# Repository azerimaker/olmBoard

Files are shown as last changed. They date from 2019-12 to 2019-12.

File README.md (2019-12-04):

# olmBoard v0.1
This is a TPS62840 based, ultra-low quiescent current, highly-efficient, breadboard-friendly buck converter module w/:
- Selectable outputs (1.8-3.3 V)
- 60nA Iq, 150nA @ 100% mode
- 20nA shutdown current 
- 750mA max output current

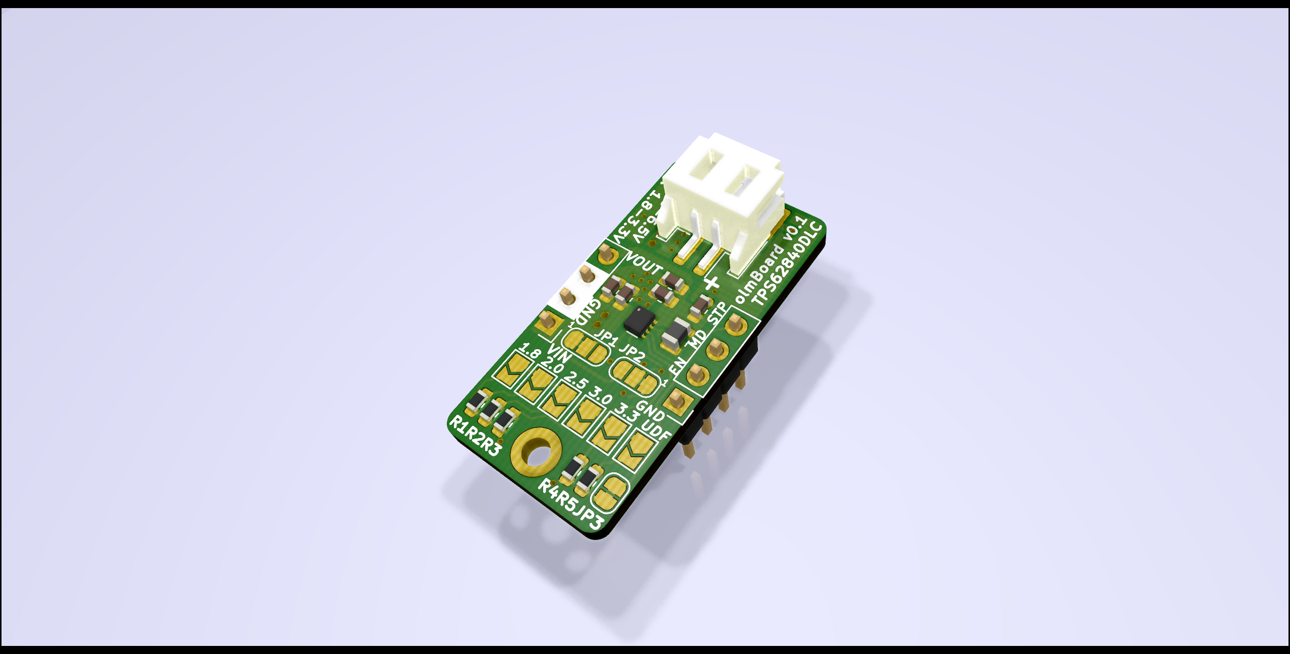
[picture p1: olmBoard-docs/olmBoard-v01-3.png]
olmBoard v0.1


Inital sweep load test results w/ 0.1A and 10 sec increments using EBD-USB load tester. The module works well up to 1A loads (short term), recommended max output current is 750mA. Voltage drop in the graph is due to the USB cable drop, actual voltage is stable around 3.3V up to 1A loads. 

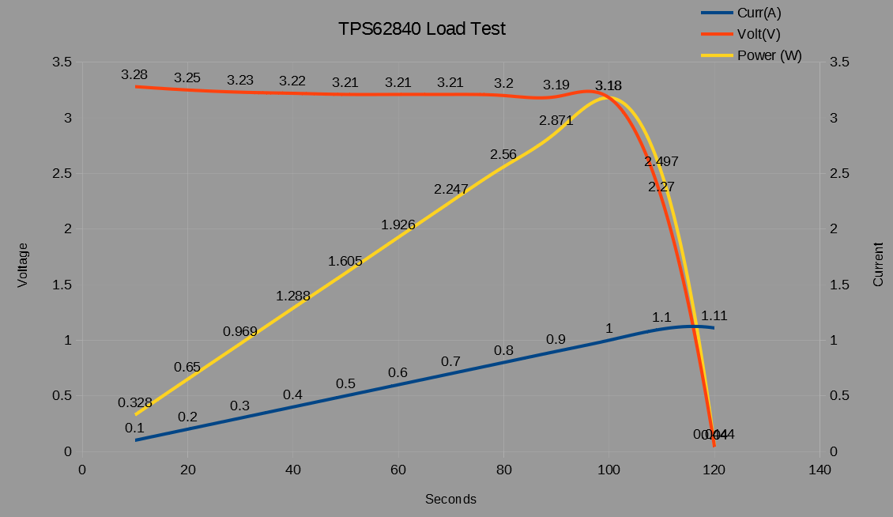
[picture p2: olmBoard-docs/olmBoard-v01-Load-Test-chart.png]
olmBoard v0.1 Load Test Chart


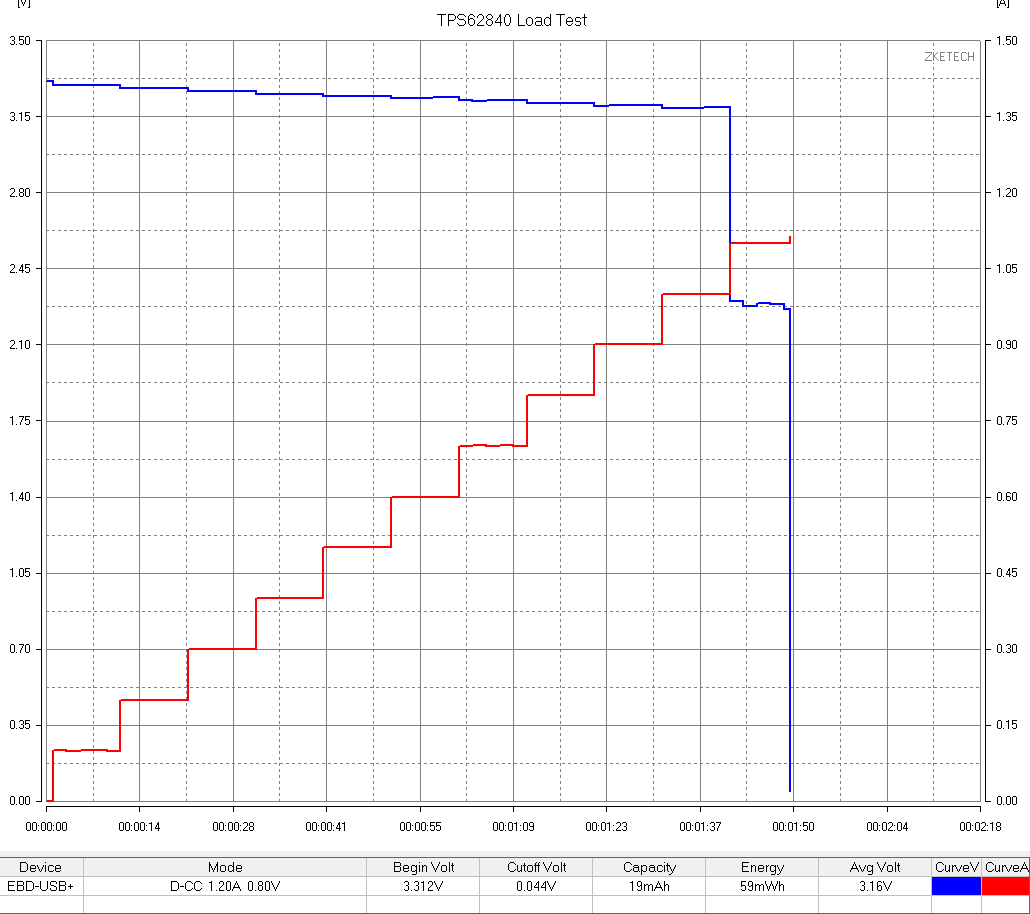
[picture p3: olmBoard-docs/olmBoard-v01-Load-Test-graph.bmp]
olmBoard v0.1 Load Test Graph


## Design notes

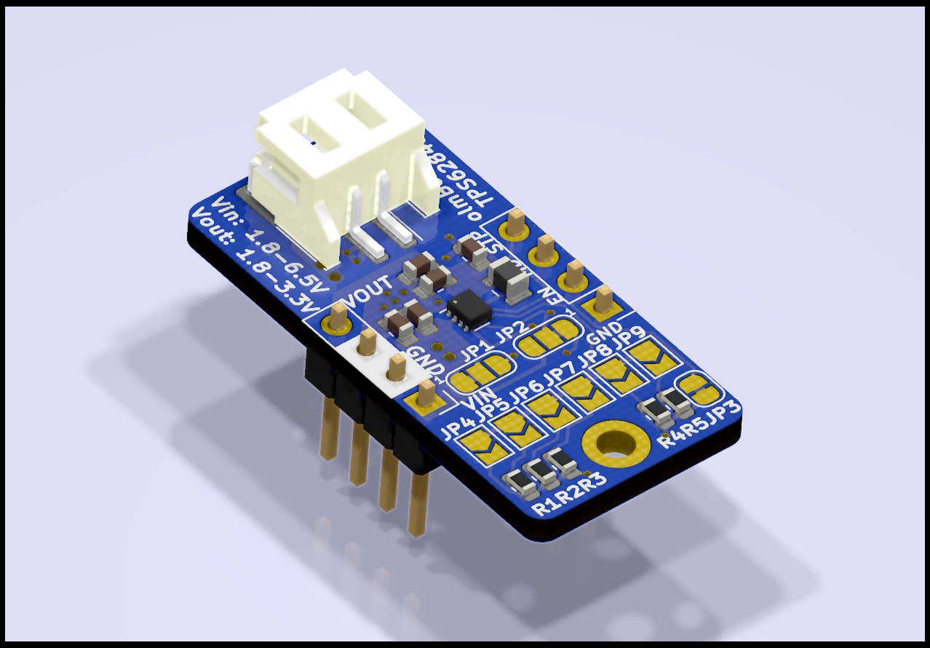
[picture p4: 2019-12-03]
olmBoard-docs/olmBoard-v01-2.png

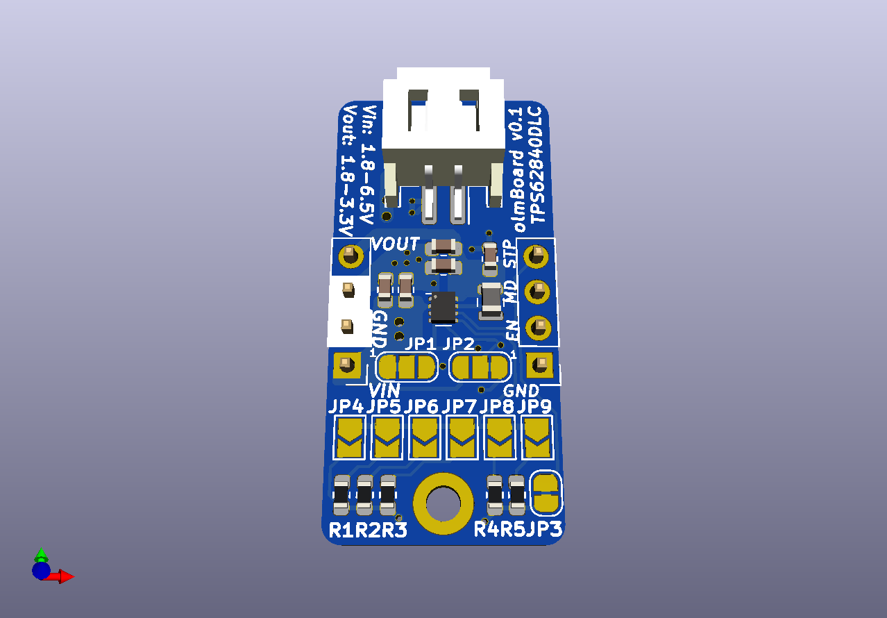
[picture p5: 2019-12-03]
olmBoard-docs/olmBoard-v01.png

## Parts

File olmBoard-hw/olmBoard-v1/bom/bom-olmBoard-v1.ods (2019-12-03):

Version: | 0.1
Tool: | Eeschema (5.1.5)-2
Component Count: | 14
Individual Components: | 12
Item | Qty | Reference(s) | Value | MPN | Footprint | URL
1 | 3 | C1, C3, C4 | 10uF | CL10A106MO8NQNC | Capacitor_SMD:C_0603_1608Metric | https://lcsc.com/product-detail/Multilayer-Ceramic-Capacitors-MLCC-SMD-SMT_Samsung-Electro-Mechanics-CL10A106MO8NQNC_C92487.html
2 | 2 | C2, C5 | 4.7uF | GRM188B31A475KE15D | Capacitor_SMD:C_0603_1608Metric | https://lcsc.com/product-detail/Multilayer-Ceramic-Capacitors-MLCC-SMD-SMT_muRata_GRM188B31A475KE15D_4-7uF-475-10-10V_C85992.html
3 | 1 | L1 | 2.2uH | TFM201610GHM-2R2MTAA | L_0806 | https://lcsc.com/product-detail/Power-Inductors_TDK-TFM201610GHM-2R2MTAA_C136243.html
4 | 1 | R1 | 1K74 | 0603WAF1741T5E | Resistor_SMD:R_0603_1608Metric | https://lcsc.com/product-detail/Chip-Resistor-Surface-Mount_UNI-ROYAL-Uniroyal-Elec-0603WAF1741T5E_C22848.html
5 | 1 | R2 | 11K5 | RC0603FR-0711K5L | Resistor_SMD:R_0603_1608Metric | https://lcsc.com/product-detail/Chip-Resistor-Surface-Mount_YAGEO-RC0603FR-0711K5L_C137802.html
6 | 1 | R3 | 52K3 | RC0603FR-0752K3L | Resistor_SMD:R_0603_1608Metric | https://lcsc.com/product-detail/Chip-Resistor-Surface-Mount_YAGEO-RC0603FR-0752K3L_C185323.html
7 | 1 | R4 | 267K | ERJ-3EKF2673V | Resistor_SMD:R_0603_1608Metric | https://lcsc.com/product-detail/Chip-Resistor-Surface-Mount_PANASONIC-ERJ3EKF2673V_C403117.html
8 | 0 | R5 | User Defined | ~ | Resistor_SMD:R_0603_1608Metric | ~
9 | 1 | U1 | TPS62840 | TPS62840DLCR | SON-8-1.5x2mm_P0.5mm | https://www.ti.com/store/ti/en/p/product/?p=TPS62840DLCR
10 | 1 | J1 | JST-PH | S2B-PH-SM4-TB(LF)(SN) | JST_PH_S2B-PH-SM4-TB_1x02-1MP_P2.00mm_Horizontal | https://www.aliexpress.com/item/32513477927.html
11 | 1 | J2 | ~ | Pin Header | PinHeader_1x04_P2.54mm_Vertical
12 | 1 | J3 | ~ | Pin Header | PinHeader_1x04_P2.54mm_Vertical

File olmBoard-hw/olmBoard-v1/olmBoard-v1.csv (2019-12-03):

Source: | C:\Users\Admin\Google-Drive-1\FILE_EXCHANGE\PCB_Projects\KiCAD\olmBoard-ULP-module\olmBoard-hw\olmBoard-v1\olmBoard-v1.sch
Date: | 11/20/2019 4:42:39 PM
Tool: | Eeschema (5.1.4)-1
Generator: | C:\Program Files\KiCad\bin\scripting\plugins/bom_csv_grouped_by_value.py
Component Count: | 25
Individual Components:
Item | Qty | Reference(s) | Value | LibPart | Footprint | Datasheet | MPN
 |  | C1 | 10uF | Device:C | Capacitor_SMD:C_0603_1608Metric | ~ | CL10A106MO8NQNC
 |  | C2 | 4.7uF | Device:C | Capacitor_SMD:C_0603_1608Metric | ~ | GRM188B31A475KE15D
 |  | C3 | 10uF | Device:C | Capacitor_SMD:C_0603_1608Metric | ~ | CL10A106MO8NQNC
 |  | C4 | 10uF | Device:C | Capacitor_SMD:C_0603_1608Metric | ~ | CL10A106MO8NQNC
 |  | C5 | 4.7uF | Device:C | Capacitor_SMD:C_0603_1608Metric | ~ | GRM188B31A475KE15D
 |  | H1 | M2-MountingHole | Mechanical:MountingHole | MountingHole:MountingHole_2.2mm_M2_DIN965_Pad | ~
 |  | J1 | JST_PH | Connector_Generic:Conn_01x02 | Connector_JST:JST_PH_S2B-PH-SM4-TB_1x02-1MP_P2.00mm_Horizontal | ~
 |  | J2 | Conn_A | Connector_Generic:Conn_01x04 | Connector_PinHeader_2.54mm:PinHeader_1x04_P2.54mm_Vertical | ~
 |  | J3 | Conn_B | Connector_Generic:Conn_01x04 | Connector_PinHeader_2.54mm:PinHeader_1x04_P2.54mm_Vertical | ~
 |  | JP1 | EN | Jumper:SolderJumper_3_Bridged12 | Jumper:SolderJumper-3_P1.3mm_Bridged12_RoundedPad1.0x1.5mm_NumberLabels | ~
 |  | JP2 | Mode | Jumper:SolderJumper_3_Bridged12 | Jumper:SolderJumper-3_P1.3mm_Bridged12_RoundedPad1.0x1.5mm_NumberLabels | ~
 |  | JP3 | STOP | Jumper:SolderJumper_2_Bridged | Jumper:SolderJumper-2_P1.3mm_Bridged_RoundedPad1.0x1.5mm | ~
 |  | JP4 | Rset | Jumper:SolderJumper_2_Open | Jumper:SolderJumper-2_P1.3mm_Open_TrianglePad1.0x1.5mm | ~
 |  | JP5 | Rset | Jumper:SolderJumper_2_Open | Jumper:SolderJumper-2_P1.3mm_Open_TrianglePad1.0x1.5mm | ~
 |  | JP6 | Rset | Jumper:SolderJumper_2_Open | Jumper:SolderJumper-2_P1.3mm_Open_TrianglePad1.0x1.5mm | ~
 |  | JP7 | Rset | Jumper:SolderJumper_2_Open | Jumper:SolderJumper-2_P1.3mm_Open_TrianglePad1.0x1.5mm | ~
 |  | JP8 | Rset | Jumper:SolderJumper_2_Bridged | Jumper:SolderJumper-2_P1.3mm_Open_TrianglePad1.0x1.5mm | ~
 |  | JP9 | Rset | Jumper:SolderJumper_2_Open | Jumper:SolderJumper-2_P1.3mm_Open_TrianglePad1.0x1.5mm | ~
 |  | L1 | 2.2uH | Device:L_Core_Ferrite | my_passives_footprints:L_0806 | ~ | TFM201610GHM-2R2MTAA
 |  | R1 | 1K74 | Device:R | Resistor_SMD:R_0603_1608Metric | ~ | 0603WAF1741T5E
 |  | R2 | 11K5 | Device:R | Resistor_SMD:R_0603_1608Metric | ~ | RC0603FR-0711K5L
 |  | R3 | 52K3 | Device:R | Resistor_SMD:R_0603_1608Metric | ~ | RC0603FR-0752K3L
 |  | R4 | 267K | Device:R | Resistor_SMD:R_0603_1608Metric | ~ | ERJ3EKF2673V
 |  | R5 | DNM | Device:R | Resistor_SMD:R_0603_1608Metric | ~
 |  | U1 | TPS62840DLC | olmBoard-v1-rescue:TPS62840DLC-olmboard | voltage_regulators:SON-8-1.5x2mm_P0.5mm | https://www.ti.com/lit/gpn/TPS62840
Collated Components:
Item | Qty | Reference(s) | Value | LibPart | Footprint | Datasheet | MPN
1 | 3 | C1, C3, C4 | 10uF | Device:C | Capacitor_SMD:C_0603_1608Metric | ~ | CL10A106MO8NQNC
2 | 2 | C2, C5 | 4.7uF | Device:C | Capacitor_SMD:C_0603_1608Metric | ~ | GRM188B31A475KE15D
3 | 1 | H1 | M2-MountingHole | Mechanical:MountingHole | MountingHole:MountingHole_2.2mm_M2_DIN965_Pad | ~
4 | 1 | J1 | JST_PH | Connector_Generic:Conn_01x02 | Connector_JST:JST_PH_S2B-PH-SM4-TB_1x02-1MP_P2.00mm_Horizontal | ~
5 | 1 | J2 | Conn_A | Connector_Generic:Conn_01x04 | Connector_PinHeader_2.54mm:PinHeader_1x04_P2.54mm_Vertical | ~
6 | 1 | J3 | Conn_B | Connector_Generic:Conn_01x04 | Connector_PinHeader_2.54mm:PinHeader_1x04_P2.54mm_Vertical | ~
7 | 1 | JP1 | EN | Jumper:SolderJumper_3_Bridged12 | Jumper:SolderJumper-3_P1.3mm_Bridged12_RoundedPad1.0x1.5mm_NumberLabels | ~
8 | 1 | JP2 | Mode | Jumper:SolderJumper_3_Bridged12 | Jumper:SolderJumper-3_P1.3mm_Bridged12_RoundedPad1.0x1.5mm_NumberLabels | ~
9 | 1 | JP3 | STOP | Jumper:SolderJumper_2_Bridged | Jumper:SolderJumper-2_P1.3mm_Bridged_RoundedPad1.0x1.5mm | ~
10 | 5 | JP4, JP5, JP6, JP7, JP9 | Rset | Jumper:SolderJumper_2_Open | Jumper:SolderJumper-2_P1.3mm_Open_TrianglePad1.0x1.5mm | ~
11 | 1 | JP8 | Rset | Jumper:SolderJumper_2_Bridged | Jumper:SolderJumper-2_P1.3mm_Open_TrianglePad1.0x1.5mm | ~
12 | 1 | L1 | 2.2uH | Device:L_Core_Ferrite | my_passives_footprints:L_0806 | ~ | TFM201610GHM-2R2MTAA
13 | 1 | R1 | 1K74 | Device:R | Resistor_SMD:R_0603_1608Metric | ~ | 0603WAF1741T5E
14 | 1 | R2 | 11K5 | Device:R | Resistor_SMD:R_0603_1608Metric | ~ | RC0603FR-0711K5L
15 | 1 | R3 | 52K3 | Device:R | Resistor_SMD:R_0603_1608Metric | ~ | RC0603FR-0752K3L
16 | 1 | R4 | 267K | Device:R | Resistor_SMD:R_0603_1608Metric | ~ | ERJ3EKF2673V
17 | 1 | R5 | DNM | Device:R | Resistor_SMD:R_0603_1608Metric | ~
18 | 1 | U1 | TPS62840DLC | olmBoard-v1-rescue:TPS62840DLC-olmboard | voltage_regulators:SON-8-1.5x2mm_P0.5mm | https://www.ti.com/lit/gpn/TPS62840

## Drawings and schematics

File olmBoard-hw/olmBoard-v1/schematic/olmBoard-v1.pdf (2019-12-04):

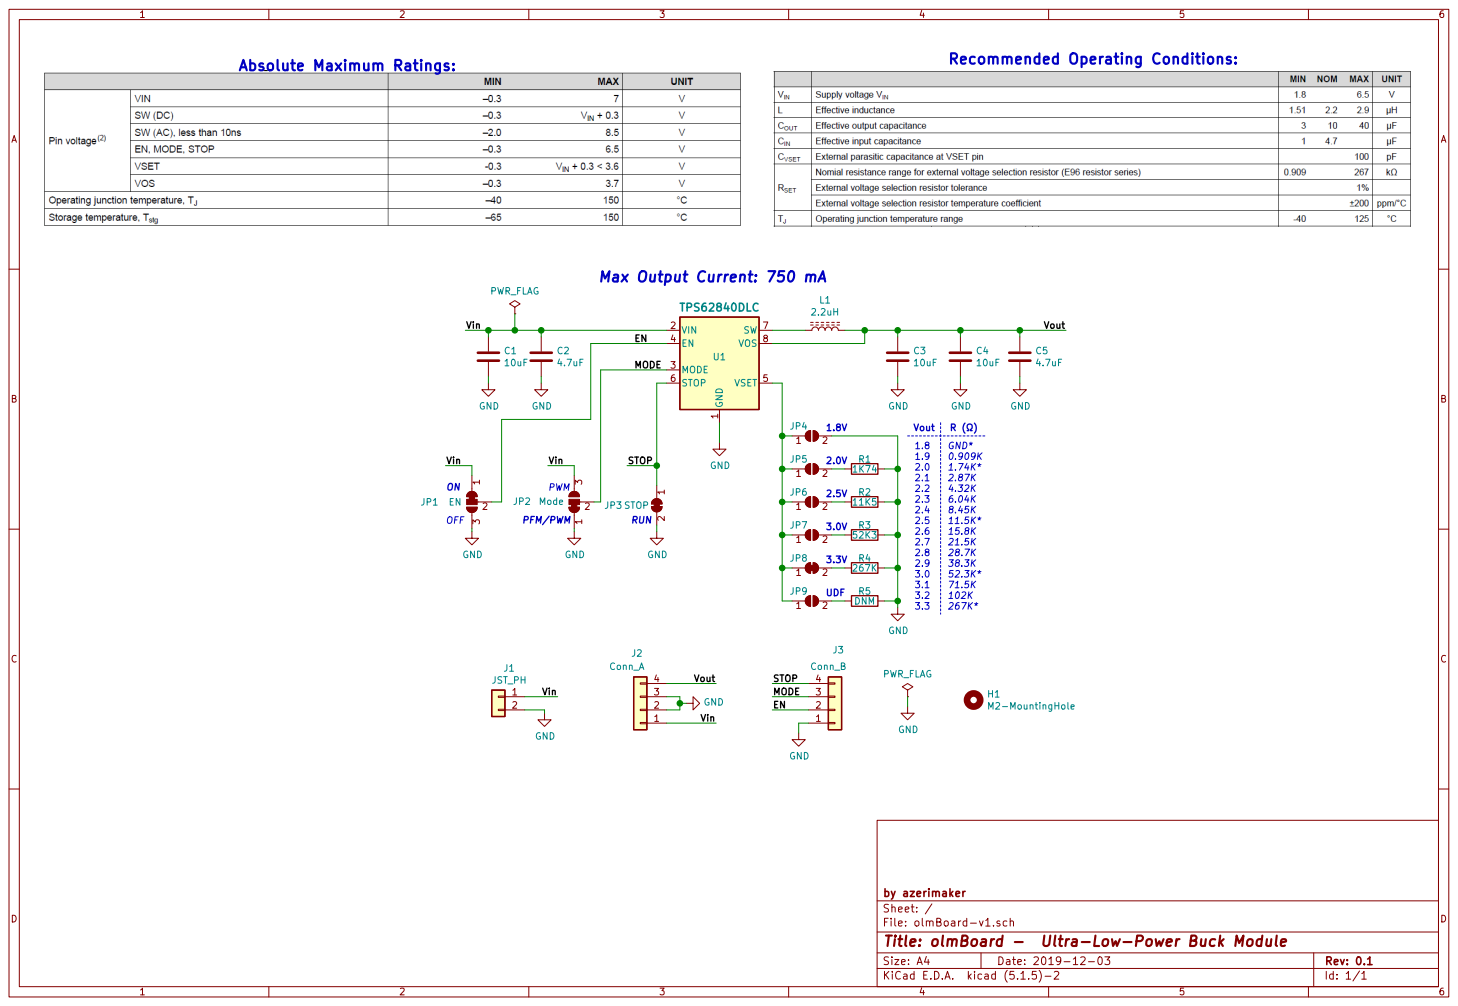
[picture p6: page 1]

1 VIN 2 MODE 3 EN 4 VSET 5 STOP 6 SW 7 VOS 8 U1 TPS62840DLC

File: olmBoard-v1.sch Sheet: / by azerimaker

Id: 1/1 Title: olmBoard - Ultra-Low-Power Buck Module

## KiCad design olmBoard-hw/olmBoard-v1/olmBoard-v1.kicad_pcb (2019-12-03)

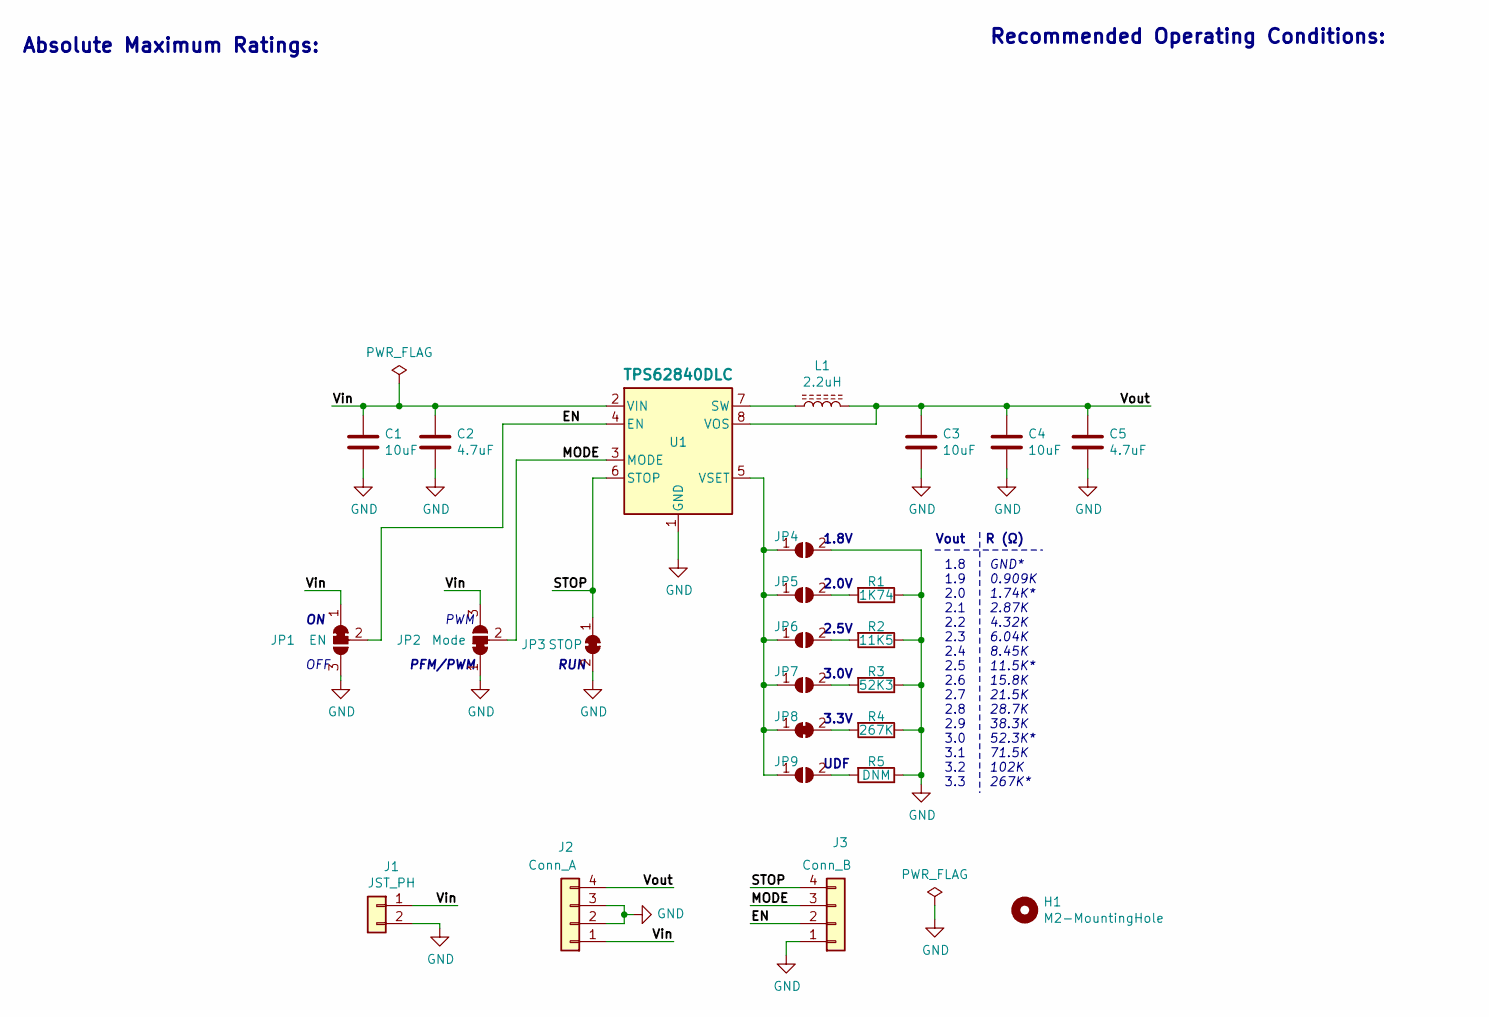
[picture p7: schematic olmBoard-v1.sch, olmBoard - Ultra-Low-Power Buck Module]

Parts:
C1, C3, C4: 10uF; C_0603_1608Metric; MPN CL10A106MO8NQNC
C2, C5: 4.7uF; C_0603_1608Metric; MPN GRM188B31A475KE15D
H1: M2-MountingHole; MountingHole_2.2mm_M2_DIN965_Pad
J1: JST_PH; JST_PH_S2B-PH-SM4-TB_1x02-1MP_P2.00mm_Horizontal
J2: Conn_A; PinHeader_1x04_P2.54mm_Vertical
J3: Conn_B; PinHeader_1x04_P2.54mm_Vertical
JP1: EN; SolderJumper-3_P1.3mm_Bridged12_RoundedPad1.0x1.5mm_NumberL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
JP2: Mode; SolderJumper-3_P1.3mm_Bridged12_RoundedPad1.0x1.5mm_NumberL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
JP3: STOP; SolderJumper-2_P1.3mm_Bridged_RoundedPad1.0x1.5mm
JP4, JP5, JP6, JP7, JP8, JP9: Rset; SolderJumper-2_P1.3mm_Open_TrianglePad1.0x1.5mm
L1: 2.2uH; L_0806; MPN TFM201610GHM-2R2MTAA
R1: 1K74; R_0603_1608Metric; MPN 0603WAF1741T5E
R2: 11K5; R_0603_1608Metric; MPN RC0603FR-0711K5L
R3: 52K3; R_0603_1608Metric; MPN RC0603FR-0752K3L
R4: 267K; R_0603_1608Metric; MPN ERJ3EKF2673V
R5: DNM; R_0603_1608Metric
U1: TPS62840DLC; SON-8-1.5x2mm_P0.5mm

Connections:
/EN: J3.2, JP1.2 (C), U1.4 (EN)
/MODE: J3.3, JP2.2 (C), U1.3 (MODE)
/STOP: J3.4, JP3.1 (A), U1.6 (STOP)
/Vin: C1.1, C2.1, J1.1, J2.1, JP1.1 (A), JP2.3 (B), U1.2 (VIN)
/Vout: C3.1, C4.1, C5.1, J2.4, L1.2, U1.8 (VOS)
GND: C1.2, C2.2, C3.2, C4.2, C5.2, J1.2, J2.2, J2.3, J3.1, JP1.3 (B), JP2.1 (A), JP3.2 (B), JP4.2 (B), R1.1, R2.1, R3.1, R4.1, R5.1, U1.1 (GND)
unnamed: JP4.1 (A), JP5.1 (A), JP6.1 (A), JP7.1 (A), JP8.1 (A), JP9.1 (A), U1.5 (VSET)
unnamed: JP5.2 (B), R1.2
unnamed: JP6.2 (B), R2.2
unnamed: JP7.2 (B), R3.2
unnamed: JP8.2 (B), R4.2
unnamed: JP9.2 (B), R5.2
unnamed: L1.1, U1.7 (SW)

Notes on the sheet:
1.8 1.9 2.0 2.1 2.2 2.3 2.4 2.5 2.6 2.7 2.8 2.9 3.0 3.1 3.2 3.3
1.8V
2.0V
2.5V
3.0V
3.3V
UDF
Vout R (Ω)
GND* 0.909K 1.74K* 2.87K 4.32K 6.04K 8.45K 11.5K* 15.8K 21.5K 28.7K 38.3K 52.3K* 71.5K 102K 267K*
PFM/PWM
PWM
OFF
RUN
Absolute Maximum Ratings:
Recommended Operating Conditions:

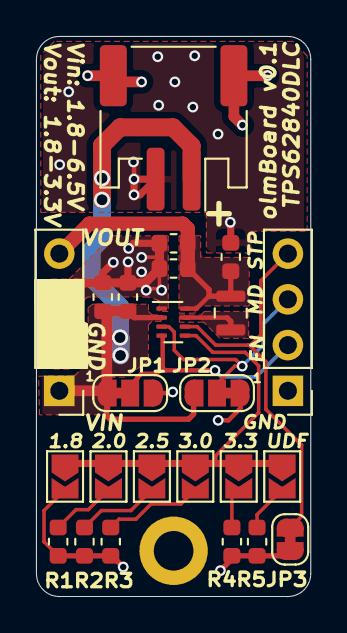
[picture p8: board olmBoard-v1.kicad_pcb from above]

Board: 2 copper layers, 15.2 x 31.1 mm, 25 parts (0 on the bottom side), 13 nets.

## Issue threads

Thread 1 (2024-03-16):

Any plans/schedule for a next bunch of boards?

boaks, 2024-03-16:
In order to combine this ULP buck with an nRF9160, I'm looking for a source to buy a "handfull" of them.
Until now I was only able to buy and test a single one.

So, are there any plans to produce a new bunch of them?

azerimaker, 2024-03-16:
Hi @boaks ,

thank you for your message here. I'm guessing the first sample passed the test successfully. No problem.
Please email me the required amount (makertronika [at] gmail.com) and I can try to build it next week.

Cheers,
Orkhan

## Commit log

2019-12-03 Design files added
    Version v0.1
    [bom-olmBoard-v1.ods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]
2019-12-03 BOM update
    [bom-olmBoard-v1.ods]
2019-12-04 Test results added
    [olmBoard-v1.sch]
